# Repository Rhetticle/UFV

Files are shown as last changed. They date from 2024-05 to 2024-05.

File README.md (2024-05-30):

<p align="center">
  
</p>

# UFV (Unmanned FireFighting Vehicle)
Unmanned firefighting vehicle as part of UQ's ENGG1100 group project course. The group I was a part of (Team White) was awarded first place for achieving a demonstration score of 19.6/20.

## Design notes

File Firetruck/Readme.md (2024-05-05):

# Receiver
<p align="center">
  
</p>
<p align="center">
  
</p>

This PCB was mounted inside the cabin of the UFV an listened for data to be sent by the controller. On receiving the joystick positions, the Arduino Nano set the correct PWM signal to the motor drivers in order to move the
wheels/nozzle motors in the correct direction with the correct speed. The PCB was designed in Kicad and manufactured by JLCPCB.

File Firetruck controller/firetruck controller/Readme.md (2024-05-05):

# Controller
<p align="center">
  
</p>
<p align="center">
  
</p>

The controller was used to control the UFV's forward/backward movement as well as the nozzle yaw and pitch and the pump. The controller PCB uses and STM32Gxx microcontroller to monitor joystick positions and transmits this out via I2C
through a standard USB cable where D-/D+ lines are used for SDA and SCL. On power up, the controller sends a random string of characters to the receiving board mounted on the UFV and waits for them to be echoed back as a form of
communication integrity/error checking.

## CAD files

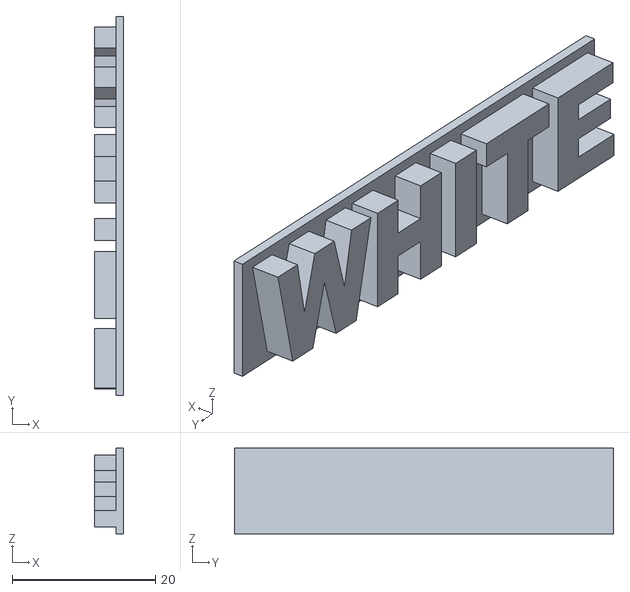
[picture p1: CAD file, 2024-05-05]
3D Models and STL/Controller STL/White.stl
4.00 x 53.0 x 12.0

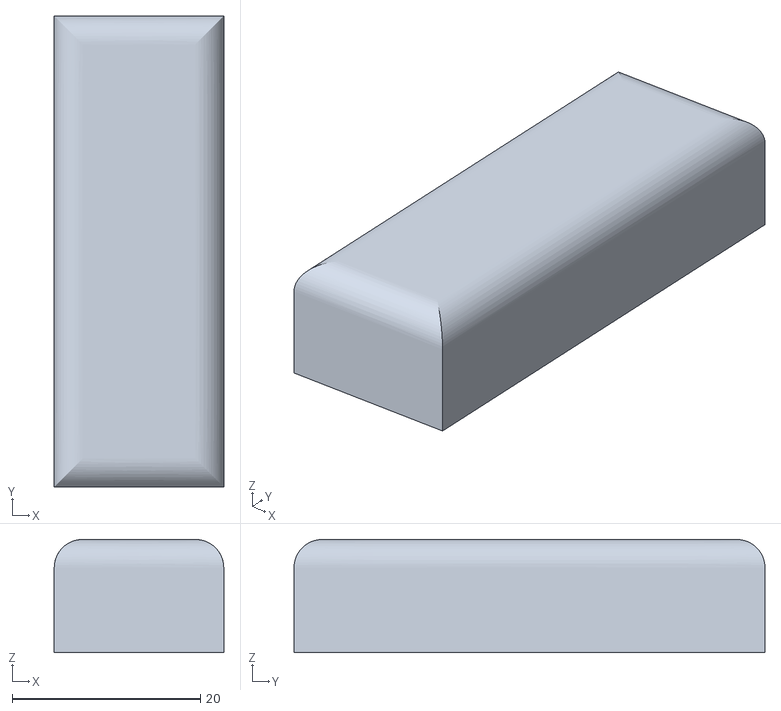
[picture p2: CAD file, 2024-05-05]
3D Models and STL/Firetruck Head/Duck Stand.stl
18.0 x 50.0 x 12.0

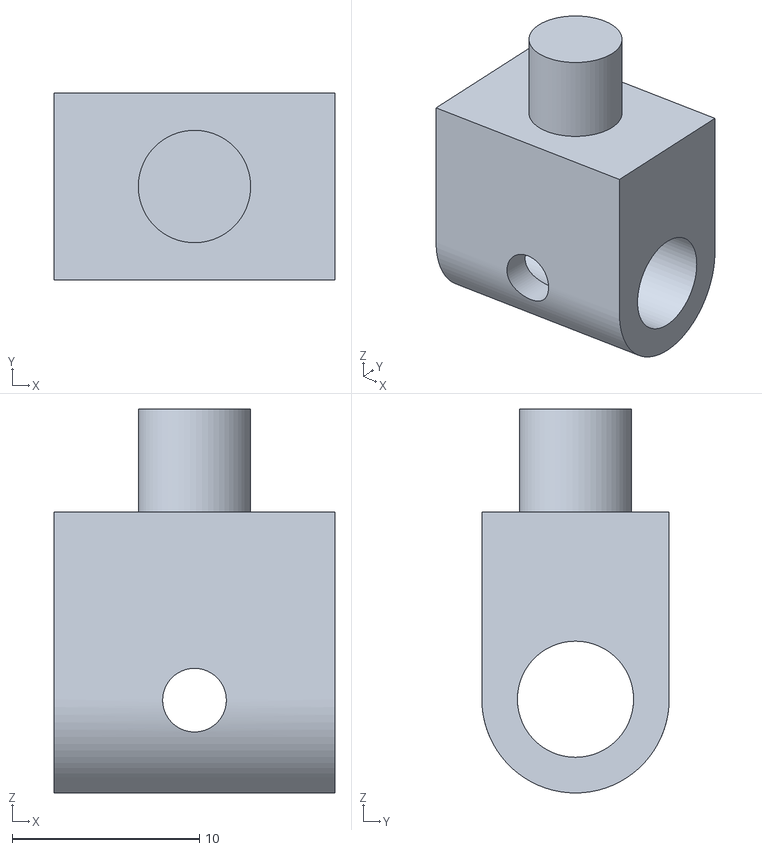
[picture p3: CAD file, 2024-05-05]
3D Models and STL/Guide wheel stuff/Block.stl
15.0 x 10.0 x 20.5

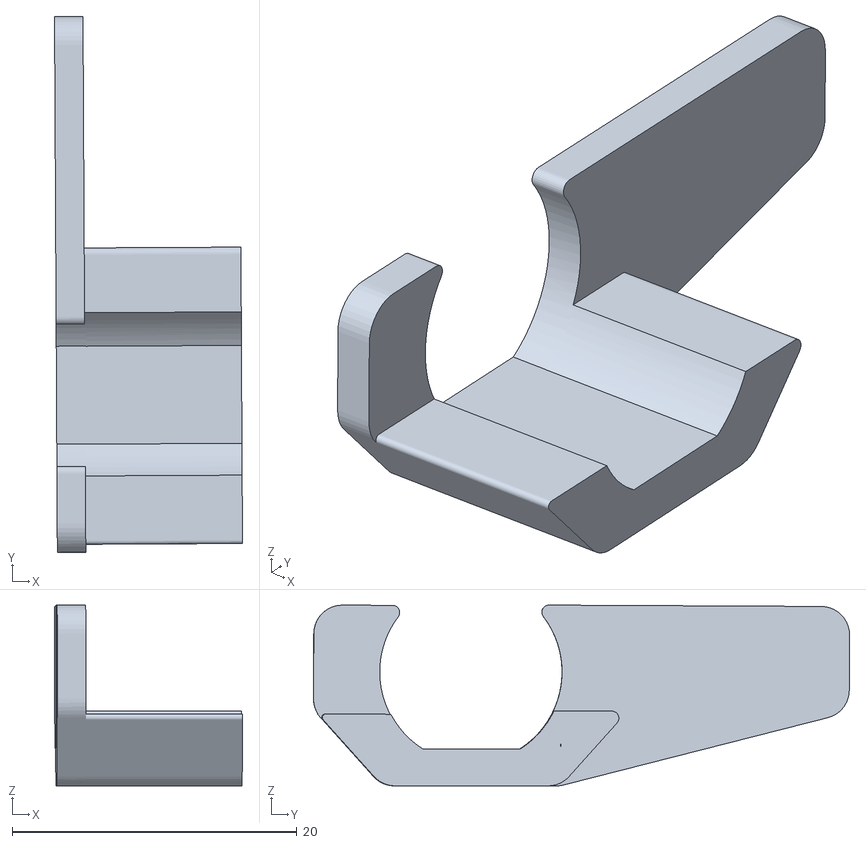
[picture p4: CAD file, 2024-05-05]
3D Models and STL/Pitch stuff/Mounting bracket.stl
13.2 x 37.6 x 12.7

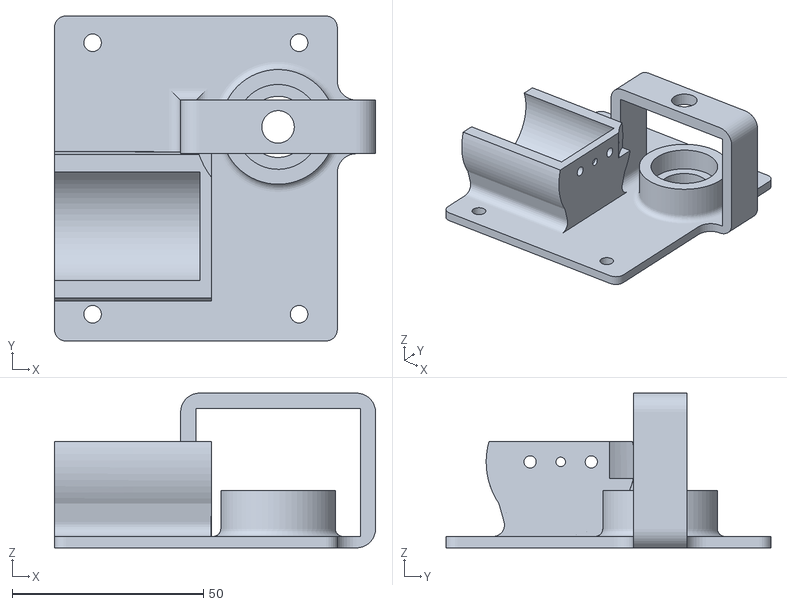
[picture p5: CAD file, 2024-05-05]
3D Models and STL/Worm Drive/Base Plate.stl
84.0 x 85.0 x 40.5

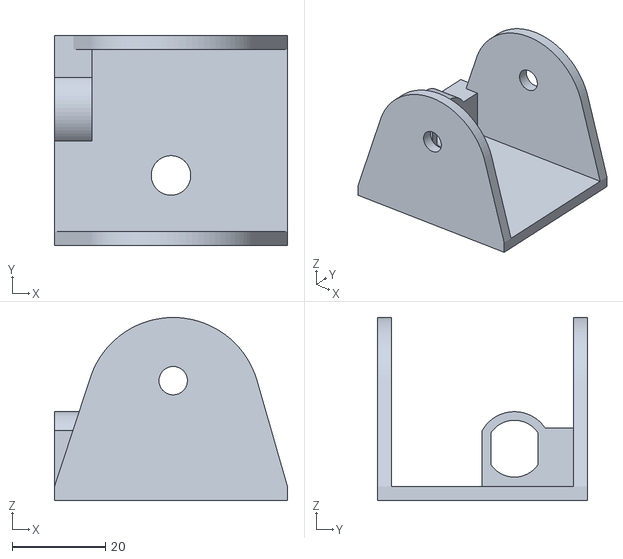
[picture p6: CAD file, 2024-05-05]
3D Models and STL/Worm pitch/Platform.stl
50.0 x 45.0 x 39.3

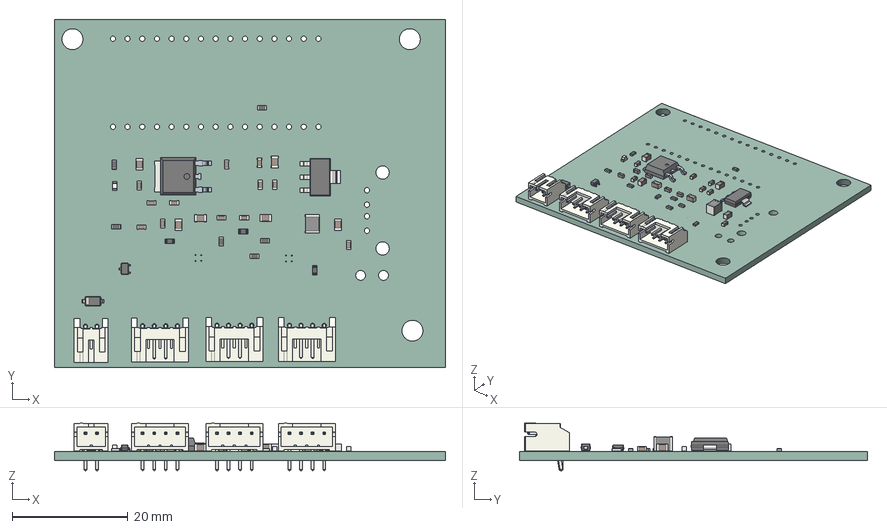
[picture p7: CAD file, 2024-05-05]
Firetruck/Firetruck/Firetruck.step
67.7 x 60.2 x 8.25 mm
PCB

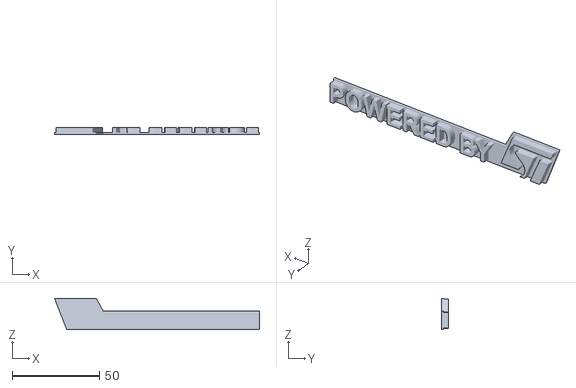
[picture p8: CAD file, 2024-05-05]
3D Models and STL/Controller STL/Powered by ST.stl
117.6 x 4.00 x 18.0

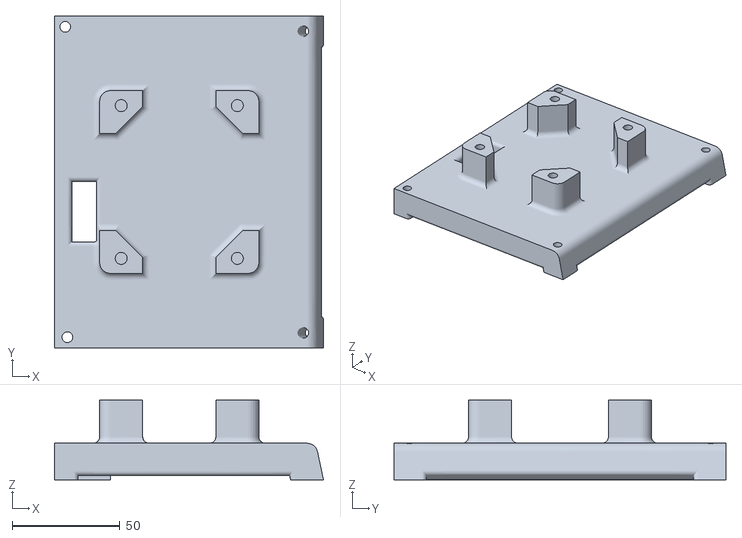
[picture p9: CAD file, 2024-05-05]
3D Models and STL/Firetruck Head/Firetruck top.stl
125.0 x 154.3 x 37.0

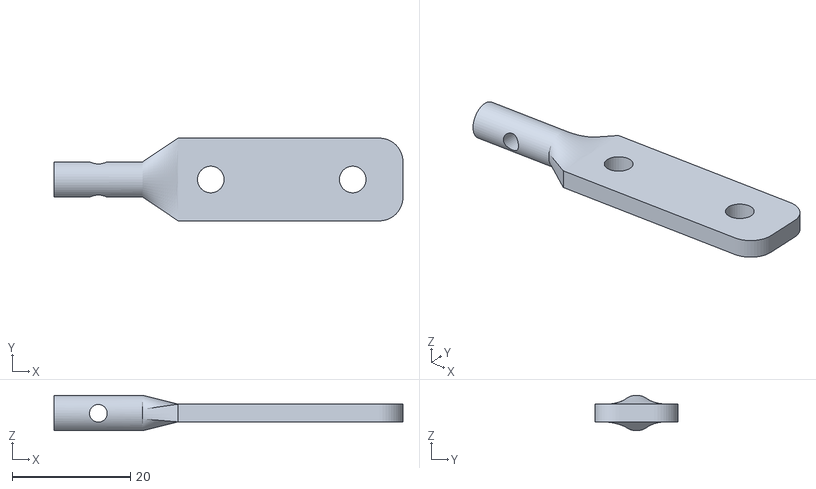
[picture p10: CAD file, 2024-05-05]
3D Models and STL/Guide wheel stuff/Adapter plate.stl
59.0 x 14.0 x 6.00

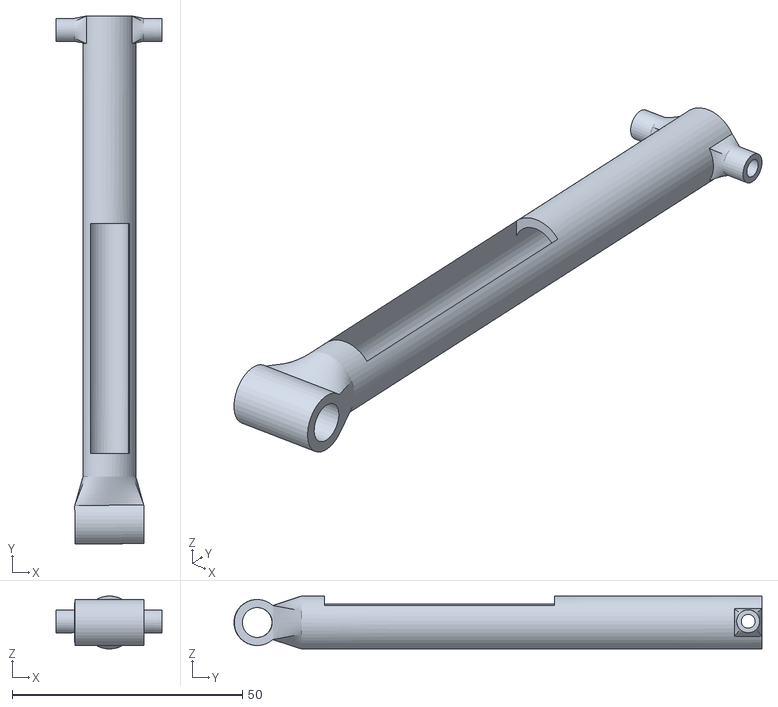
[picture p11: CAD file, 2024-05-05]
3D Models and STL/Pitch stuff/Nozzle guide.stl
23.0 x 114.6 x 11.5

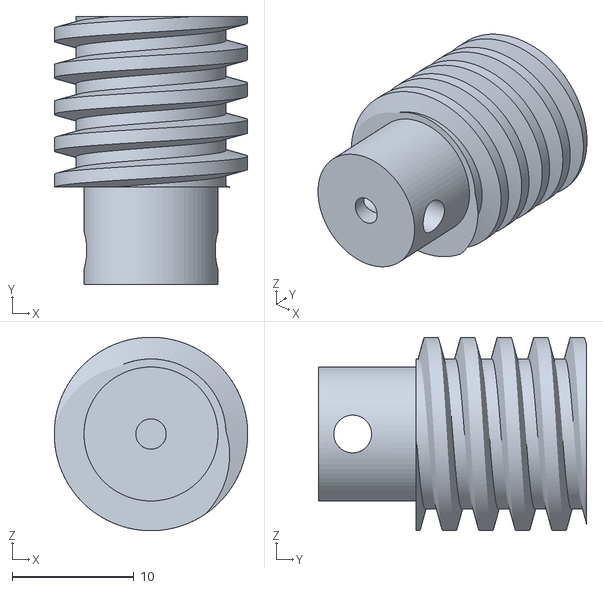
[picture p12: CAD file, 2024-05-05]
3D Models and STL/Worm Drive/Worm Gear.stl
15.9 x 22.0 x 15.9

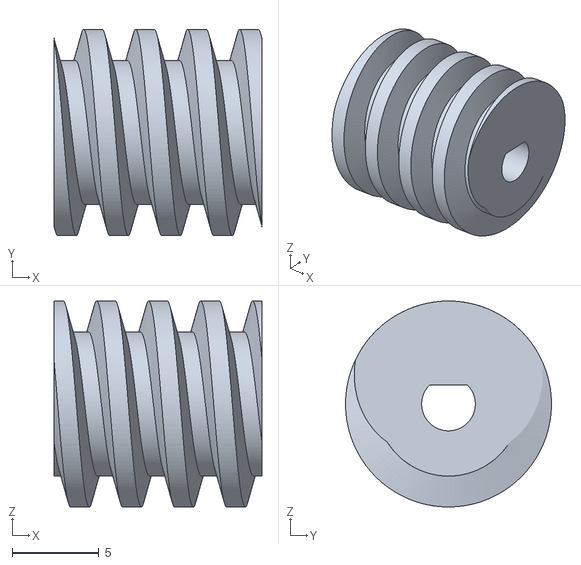
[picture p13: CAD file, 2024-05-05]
3D Models and STL/Worm pitch/Worm gear.stl
12.0 x 11.9 x 11.9

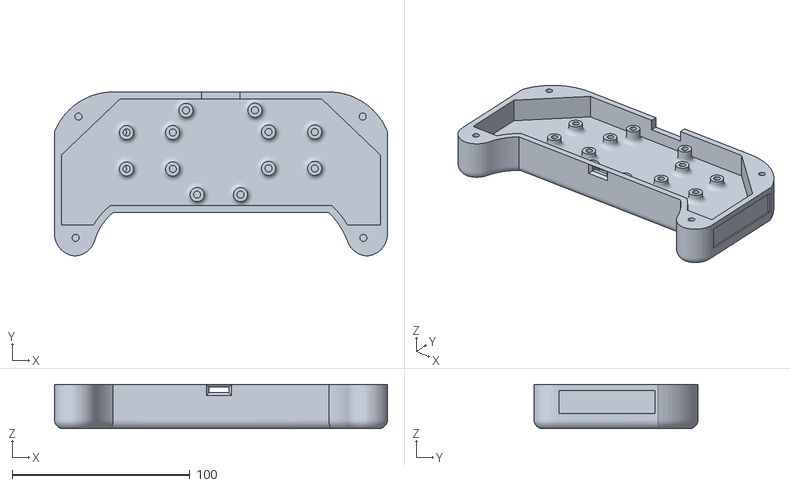
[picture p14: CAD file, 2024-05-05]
3D Models and STL/Controller STL/Controller Base.stl
187.5 x 92.4 x 25.0

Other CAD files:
3D Models and STL/Firetruck Head/Firetruck front.stl
3D Models and STL/Pitch stuff/Servo arm.stl
3D Models and STL/Worm Drive/Worm Wheel.stl
3D Models and STL/Worm pitch/Worm wheel.stl
3D Models and STL/Controller STL/Controller Top.stl
3D Models and STL/Firetruck Head/Base.f3d
3D Models and STL/Firetruck Head/Firetruck Head v22.iges
3D Models and STL/Firetruck Head/Firetruck back.stl
3D Models and STL/Firetruck Head/Guide wheel adapter.stl
3D Models and STL/Firetruck Head/Motor Gear.stl
3D Models and STL/Firetruck Head/Nozzle Gear.stl
3D Models and STL/Firetruck Head/Nozzle Platform.stl
3D Models and STL/Firetruck Head/Number Plate.stl
3D Models and STL/Firetruck Head/Platform.stl
3D Models and STL/Firetruck Head/Test Bracket.stl
3D Models and STL/Firetruck Head/Worm Gear.stl
3D Models and STL/Firetruck Head/Worm Wheel.stl
3D Models and STL/Pitch stuff/Base ring.stl

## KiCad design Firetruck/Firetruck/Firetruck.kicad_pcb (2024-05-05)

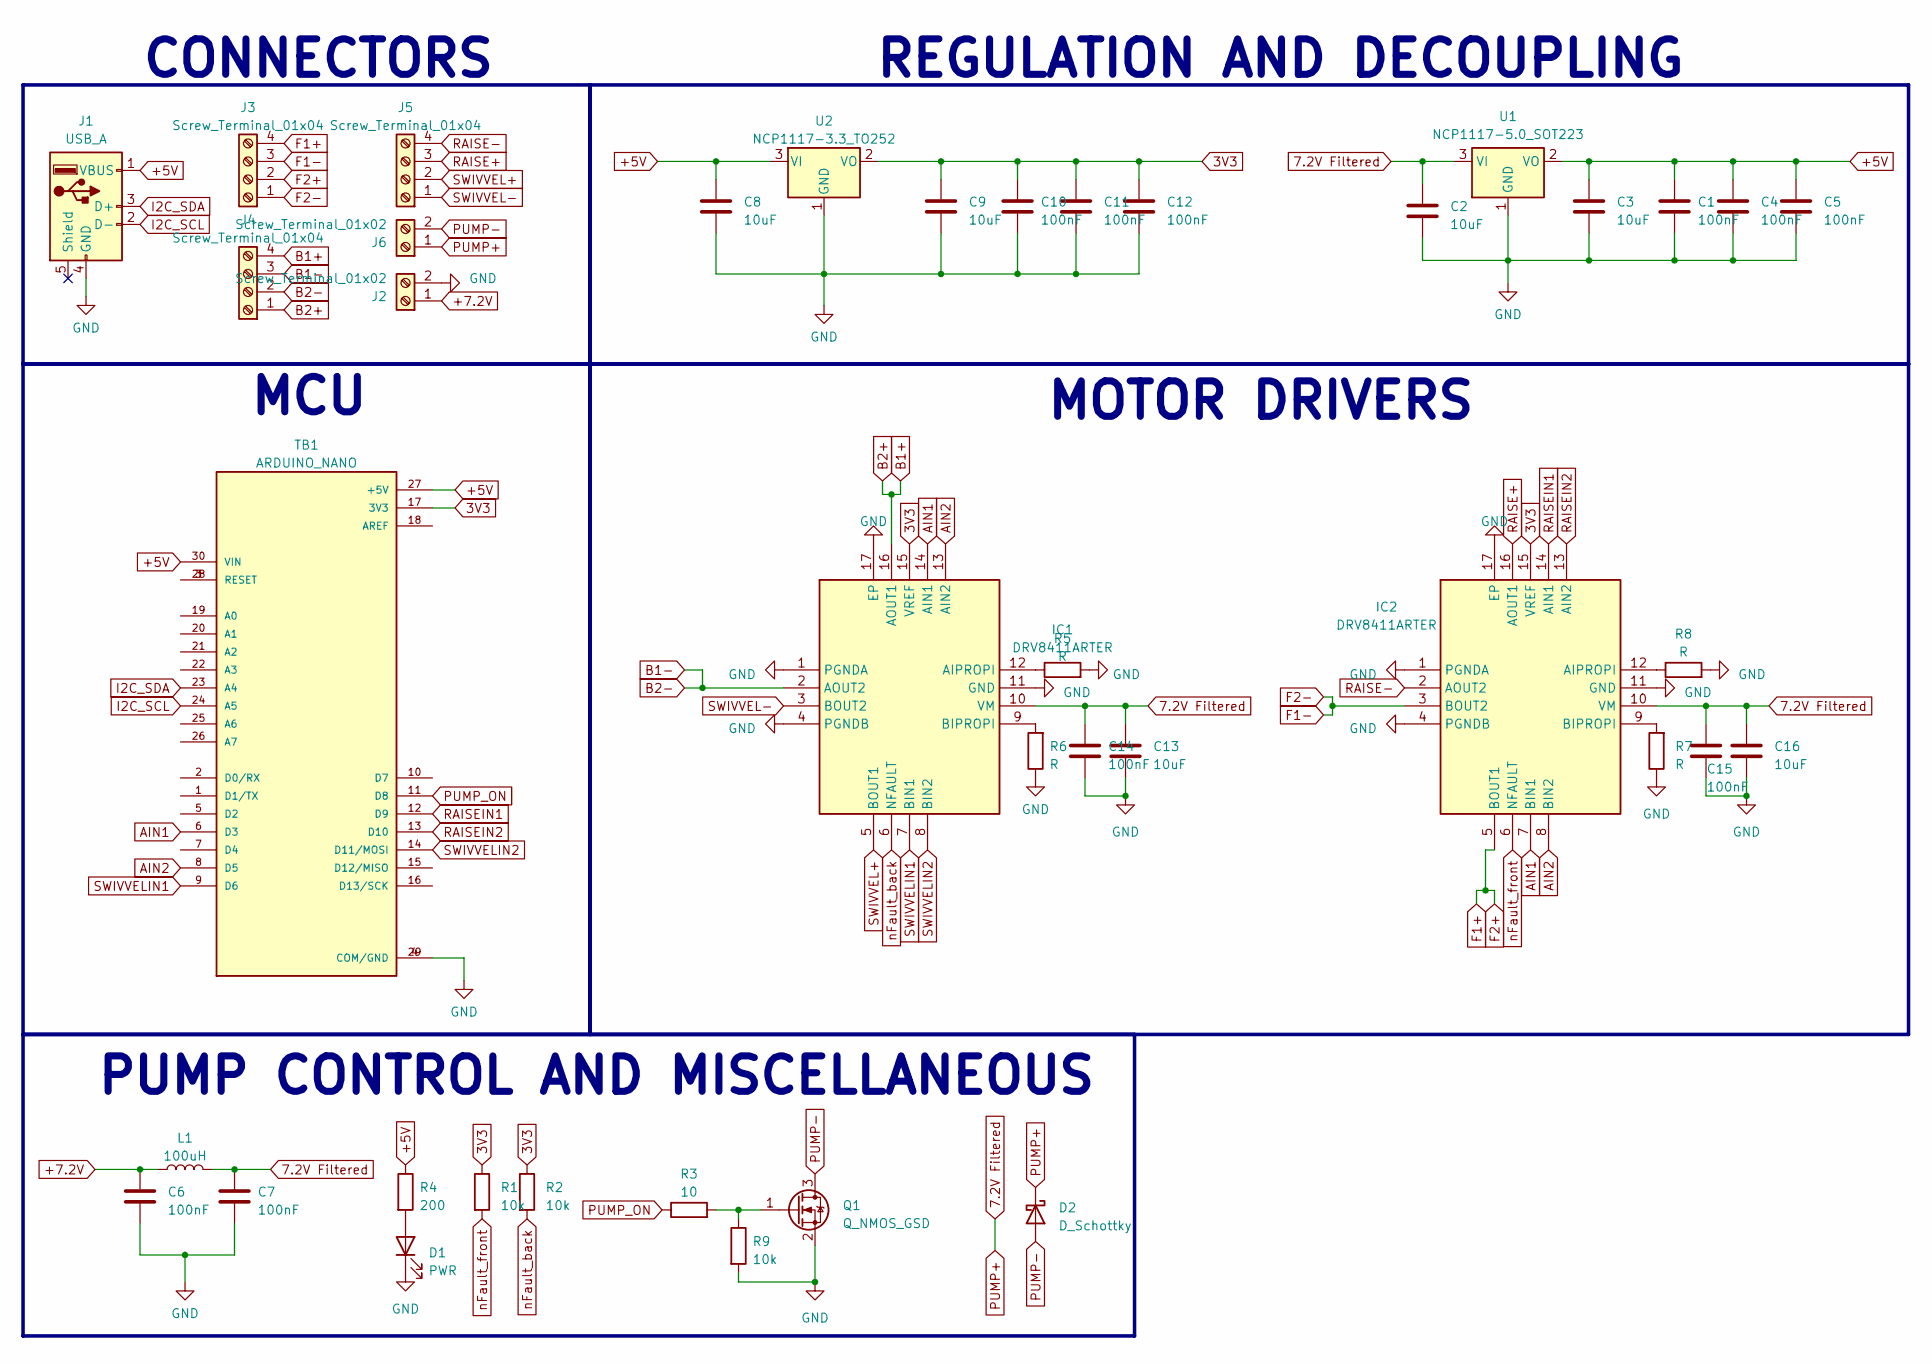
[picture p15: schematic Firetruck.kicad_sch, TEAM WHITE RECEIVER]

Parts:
C1, C4, C5, C6, C7, C10, C11, C12, C14, C15: 100nF; C_0603_1608Metric
C2, C3, C9, C13, C16: 10uF; C_0805_2012Metric
C8: 10uF; C_0603_1608Metric
D1: PWR; LED_0603_1608Metric
D2: D_Schottky; D_SOD-123
IC1, IC2: DRV8411ARTER; QFN50P300X300X80-17N-D; Manufacturer_Part_Number DRV8411ARTER; Mouser Part Number 595-DRV8411ARTER
J1: USB_A; USB-2.0-TYPE-A
J2: Screw_Terminal_01x02; JST_VH_B2PS-VH_1x02_P3.96mm_Horizontal
J3, J4, J5: Screw_Terminal_01x04; JST_PH_S4B-PH-K_1x04_P2.00mm_Horizontal
J6: Screw_Terminal_01x02; JST_PH_S2B-PH-K_1x02_P2.00mm_Horizontal
L1: 100uH; L_1210_3225Metric
Q1: Q_NMOS_GSD; SOT-323_SC-70_Handsoldering
R1, R2, R9: 10k; R_0603_1608Metric
R3: 10; R_0603_1608Metric
R4: 200; R_0603_1608Metric
R5, R6, R7, R8: R; R_0603_1608Metric
TB1: ARDUINO_NANO; SHIELD_ARDUINO_NANO
U1: NCP1117-5.0_SOT223; SOT-223-3_TabPin2
U2: NCP1117-3.3_TO252; TO-252-2

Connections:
3V3: C9.1, C10.1, C11.1, C12.1, IC1.15 (VREF), IC2.15 (VREF), R1.1, R2.1, TB1.17 (3V3), U2.2 (VO)
7.2V Filtered: C2.1, C7.1, C13.1, C14.1, C15.1, C16.1, D2.1 (K), IC1.10 (VM), IC2.10 (VM), J6.1, L1.2, U1.3 (VI); also elsewhere on the board
+5V: C1.1, C3.1, C4.1, C5.1, C8.1, J1.1 (VBUS), R4.1, TB1.27 (+5V), TB1.30 (VIN), U1.2 (VO), U2.3 (VI)
+7.2V: C6.1, J2.1, L1.1
AIN1: IC1.14 (AIN1), IC2.7 (BIN1), TB1.6 (D3)
AIN2: IC1.13 (AIN2), IC2.8 (BIN2), TB1.8 (D5)
B1+: IC1.16 (AOUT1), J4.1, J4.4
B1-: IC1.2 (AOUT2), J4.2, J4.3
F1+: IC2.5 (BOUT1), J3.2, J3.4
F1-: IC2.3 (BOUT2), J3.1, J3.3
GND: C1.2, C2.2, C3.2, C4.2, C5.2, C6.2, C7.2, C8.2, C9.2, C10.2, C11.2, C12.2, C13.2, C14.2, C15.2, C16.2, D1.1 (K), IC1.1 (PGNDA), IC1.4 (PGNDB), IC1.11 (GND), IC1.17 (EP), IC2.1 (PGNDA), IC2.4 (PGNDB), IC2.11 (GND), IC2.17 (EP), J1.4 (GND), J2.2, Q1.2 (S), R5.2, R6.1, R7.1, R8.2, R9.2, TB1.4 (COM/GND), TB1.29 (COM/GND), U1.1 (GND), U2.1 (GND); also elsewhere on the board
I2C_SCL: J1.2 (D-), TB1.24 (A5)
I2C_SDA: J1.3 (D+), TB1.23 (A4)
unnamed: D1.2 (A), R4.2
unnamed: IC1.12 (AIPROPI), R5.1
unnamed: IC1.9 (BIPROPI), R6.2
unnamed: IC2.12 (AIPROPI), R8.1
unnamed: IC2.9 (BIPROPI), R7.2
unnamed: Q1.1 (G), R3.2, R9.1
unnamed: TB1.3 (RESET), TB1.28 (RESET)
PUMP-: D2.2 (A), J6.2, Q1.3 (D)
PUMP_ON: R3.1, TB1.11 (D8)
RAISE+: IC2.16 (AOUT1), J5.3
RAISE-: IC2.2 (AOUT2), J5.4
RAISEIN1: IC2.14 (AIN1), TB1.12 (D9)
RAISEIN2: IC2.13 (AIN2), TB1.13 (D10)
SWIVVEL+: IC1.5 (BOUT1), J5.2
SWIVVEL-: IC1.3 (BOUT2), J5.1
SWIVVELIN1: IC1.7 (BIN1), TB1.9 (D6)
SWIVVELIN2: IC1.8 (BIN2), TB1.14 (D11/MOSI)
nFault_back: IC1.6 (NFAULT), R2.2
nFault_front: IC2.6 (NFAULT), R1.2

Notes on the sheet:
MOTOR DRIVERS
REGULATION AND DECOUPLING
CONNECTORS
PUMP CONTROL AND MISCELLANEOUS
MCU

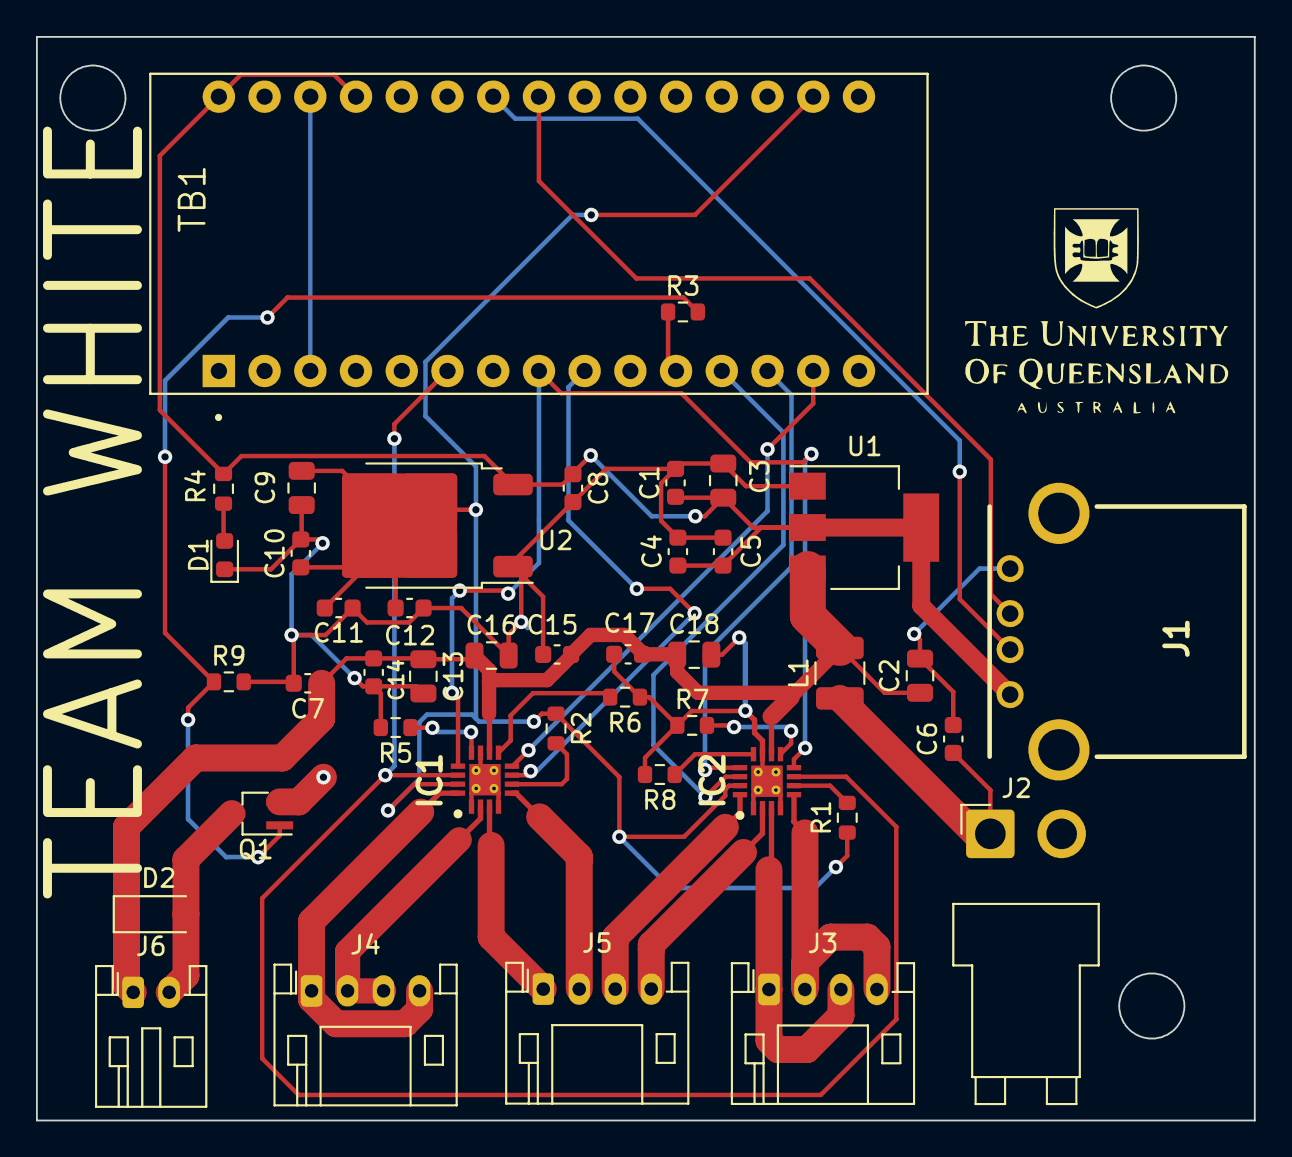
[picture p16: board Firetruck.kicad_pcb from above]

Board: 2 copper layers, 67.7 x 60.2 mm, 42 parts (0 on the bottom side), 32 nets.

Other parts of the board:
C17: 100nF; C_0603_1608Metric
C18: 10uF; C_0805_2012Metric

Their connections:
7.2V Filtered: C17.1, C18.1; also elsewhere on the board
GND: C17.2, C18.2; also elsewhere on the board

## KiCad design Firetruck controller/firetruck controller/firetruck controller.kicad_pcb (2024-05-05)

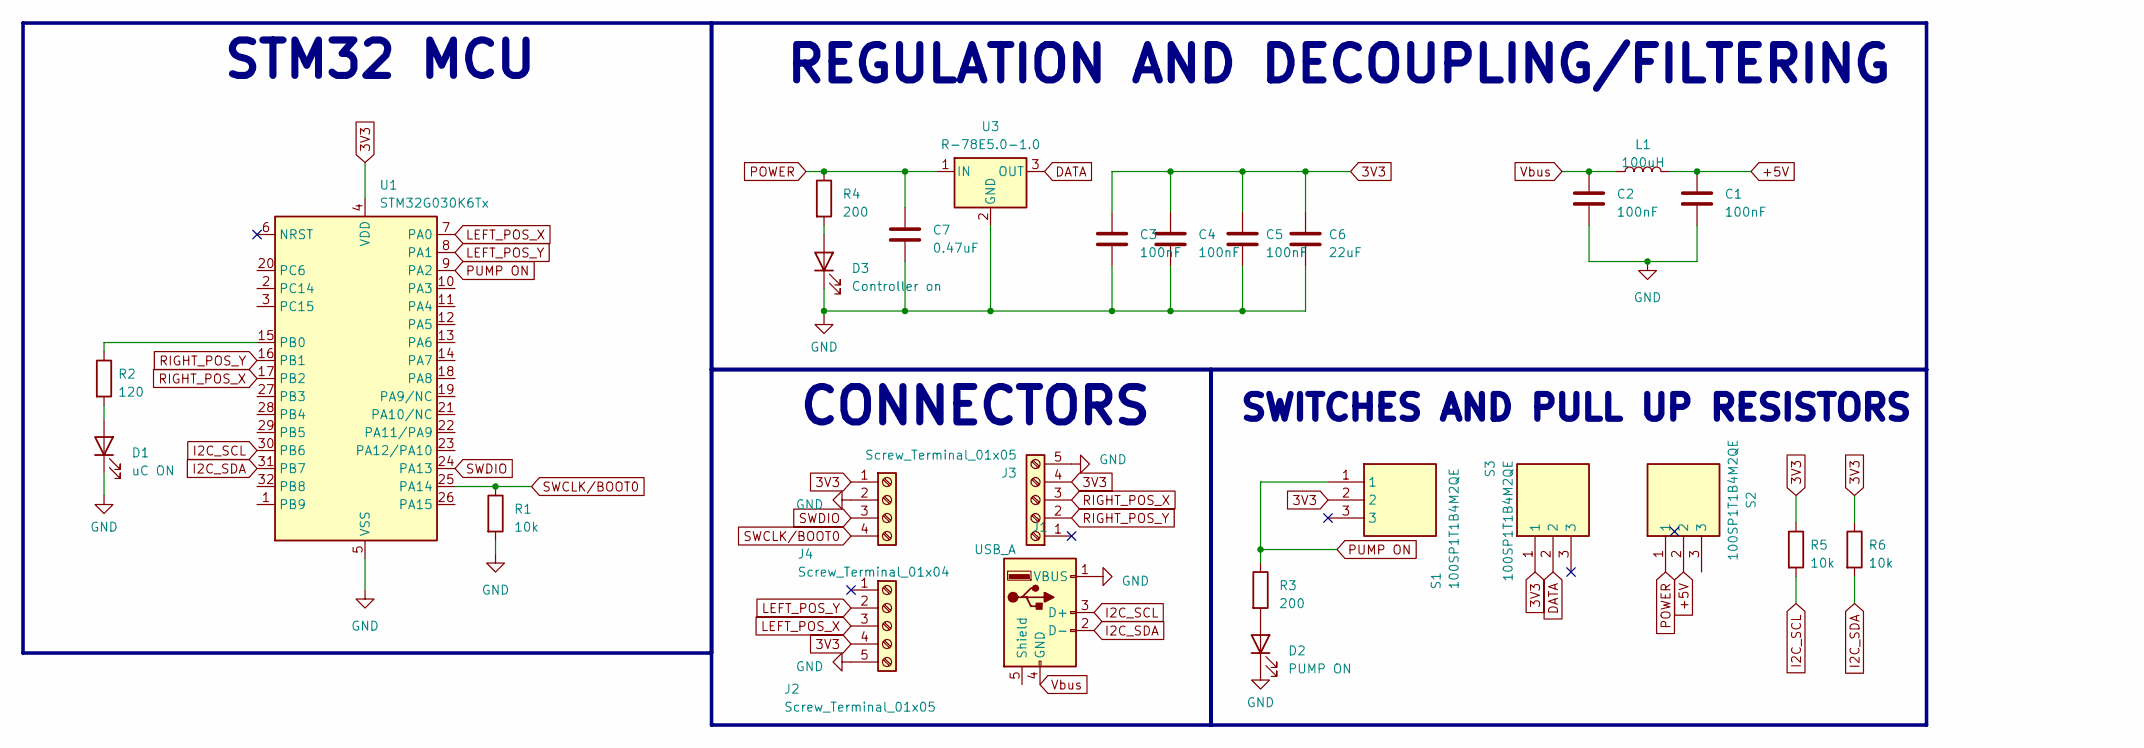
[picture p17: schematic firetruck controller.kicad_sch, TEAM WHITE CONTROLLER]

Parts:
C1, C2, C3, C4, C5: 100nF; C_0603_1608Metric
C6: 22uF; C_0805_2012Metric
C7: 0.47uF; C_0603_1608Metric
D1: uC ON; LED_D5.0mm
D2: PUMP ON; LED_D5.0mm
D3: Controller on; LED_D5.0mm
J1: USB_A; USB-2.0-TYPE-A
J2, J3: Screw_Terminal_01x05; PinSocket_1x05_P2.54mm_Horizontal
J4: Screw_Terminal_01x04; PinHeader_1x04_P2.54mm_Horizontal
L1: 100uH; L_1210_3225Metric
R1, R5, R6: 10k; R_0603_1608Metric
R2: 120; R_0603_1608Metric
R3, R4: 200; R_0603_1608Metric
S1, S2, S3: 100SP1T1B4M2QE; Manufacturer_Part_Number 100SP1T1B4M2QE; Mouser Part Number 612-100-A1421
U1: STM32G030K6Tx; LQFP-32_7x7mm_P0.8mm
U3: R-78E5.0-1.0; SOT-223

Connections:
3V3: C3.1, C4.1, C5.1, C6.1, J2.4, J3.4, J4.1, R5.1, R6.1, S1.2, S3.1, U1.4 (VDD)
+5V: C1.1, L1.2, S2.2
GND: C1.2, C2.2, C3.2, C4.2, C5.2, C6.2, C7.2, D1.1 (K), D2.1 (K), D3.1 (K), J1.1 (VBUS), J2.5, J3.5, J4.2, R1.2, U1.5 (VSS); also elsewhere on the board
I2C_SCL: J1.3 (D+), R5.2, U1.30 (PB6)
I2C_SDA: J1.2 (D-), R6.2, U1.31 (PB7)
LEFT_POS_X: J2.3, U1.7 (PA0)
LEFT_POS_Y: J2.2, U1.8 (PA1)
unnamed: D1.2 (A), R2.2
unnamed: D2.2 (A), R3.2
unnamed: D3.2 (A), R4.2
unnamed: R2.1, U1.15 (PB0)
unnamed 11: C7.1, R4.1, S2.1; also elsewhere on the board
unnamed 12: S3.2; also elsewhere on the board
PUMP ON: R3.1, S1.1, U1.9 (PA2)
RIGHT_POS_X: J3.3, U1.17 (PB2)
RIGHT_POS_Y: J3.2, U1.16 (PB1)
SWCLK/BOOT0: J4.4, R1.1, U1.25 (PA14)
SWDIO: J4.3, U1.24 (PA13)
Vbus: C2.1, J1.4 (GND), L1.1

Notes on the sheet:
REGULATION AND DECOUPLING/FILTERING
CONNECTORS
SWITCHES AND PULL UP RESISTORS
STM32 MCU

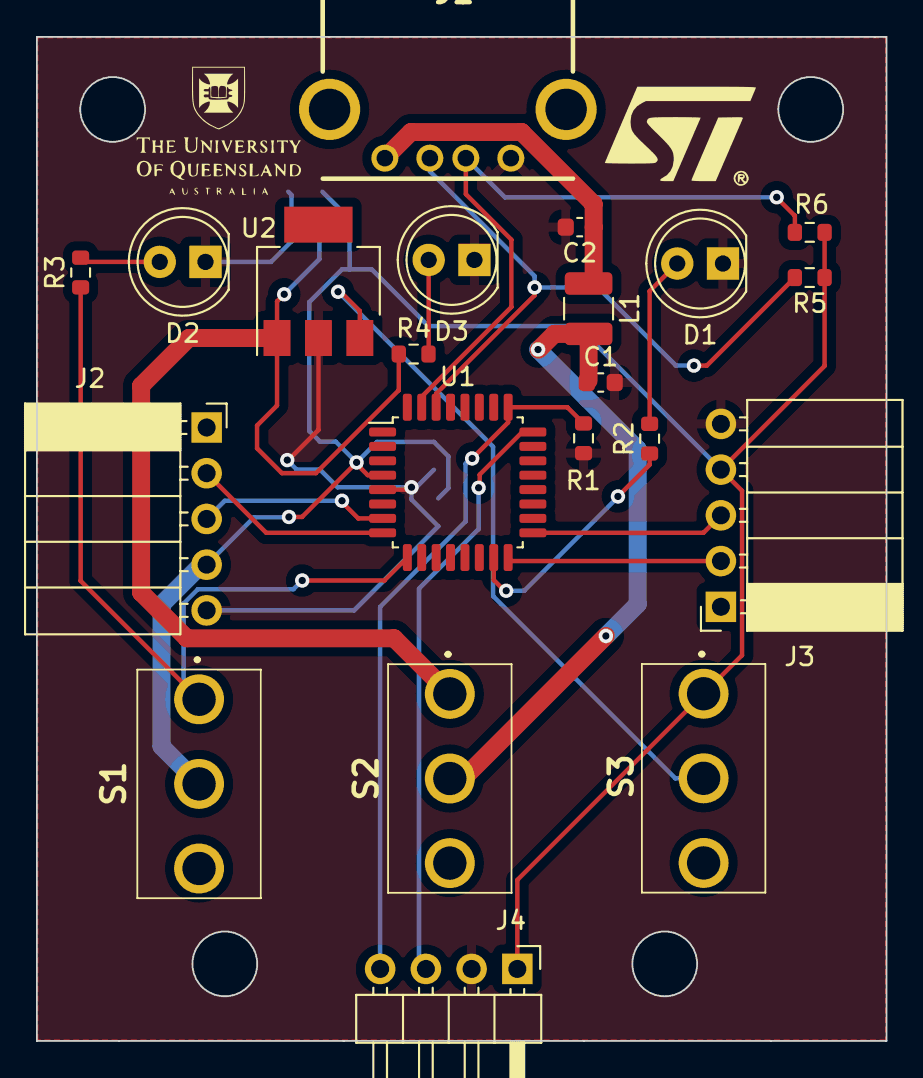
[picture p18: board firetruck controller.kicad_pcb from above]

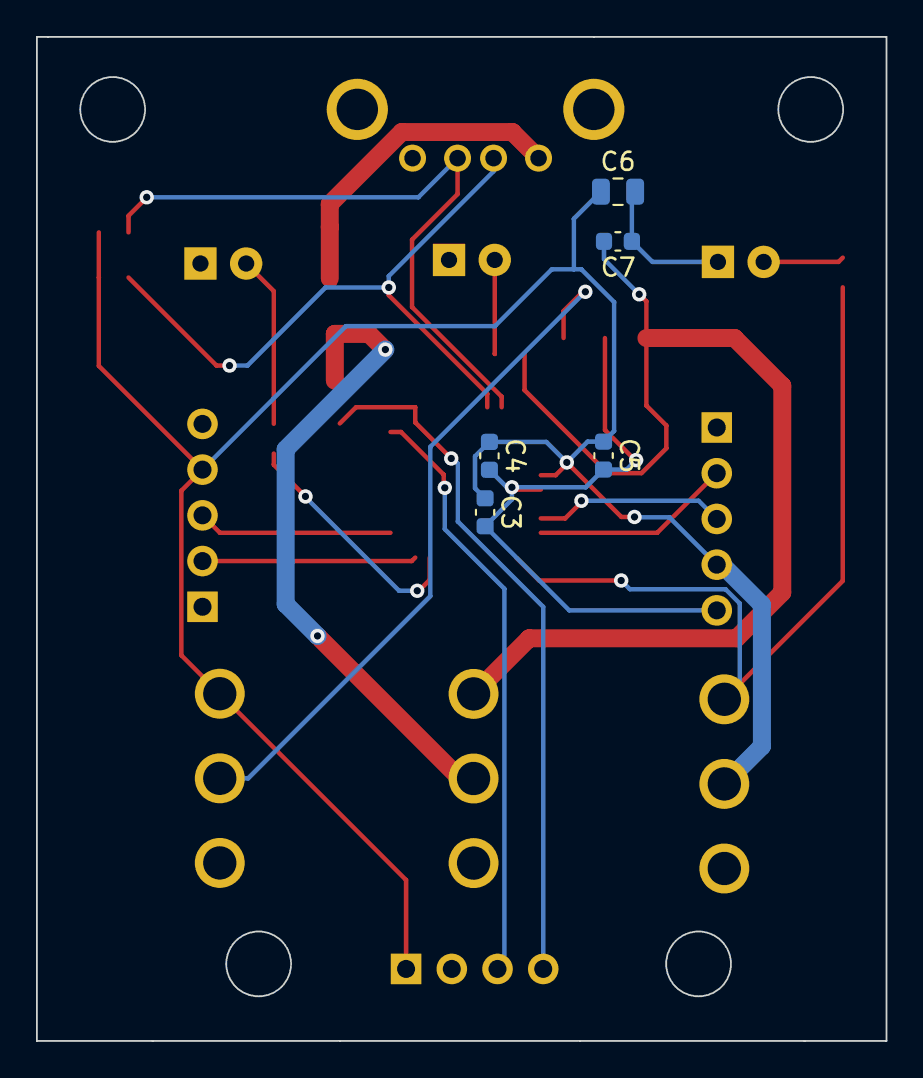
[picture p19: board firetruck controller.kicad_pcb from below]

Board: 2 copper layers, 47.2 x 55.8 mm, 26 parts (5 on the bottom side), 19 nets.

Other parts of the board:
U2: R-78E5.0-1.0; SOT-223

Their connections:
GND: U2.2 (GND); also elsewhere on the board
unnamed 11: U2.1 (IN); also elsewhere on the board
unnamed 12: U2.3 (OUT); also elsewhere on the board
